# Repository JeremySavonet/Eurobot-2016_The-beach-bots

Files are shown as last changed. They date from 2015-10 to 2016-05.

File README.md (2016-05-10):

EUROBOT 2016 - The Beach Bots
====

TODO <br><br>

<h4>HW description:</h4>
----

Board : https://www.olimex.com/Products/ARM/ST/STM32-E407/open-source-hardware <br>
Motor Driver : https://www.olimex.com/Products/RobotParts/MotorDrivers/BB-VNH3SP30/open-source-hardware<br>
WiFi IoT module : https://www.olimex.com/Products/IoT/MOD-WIFI-ESP8266/open-source-hardware<br> 
=> Github : https://github.com/espressif/esp8266_at<br>

<h4>SW description:</h4>
----

Need to test those two RTOS:<br>

<li>Freertos : https://github.com/frtos-wpan/freertos-201309/tree/master/FreeRTOS/Demo/E407</li>
<li>ChibiOS : http://chibios.org/dokuwiki/doku.php?id=chibios:documentation:start</li>
    
Chibios seems to be a better alternative than FreeRtos for severals reasons:<br>
<li>maintaining our own hal eats a lot of development time - ChibiOS comes with a hal</li>
<li>pios hal is not being widely used and tested - ChibiOS is</li>
<li>FreeRTOS relies 100% on dynamic memory allocation (heap) - ChibiOS can do static as well as dynamic memory (even mixed)</li>
<li>FreeRTOS api is not type safe (mutex / semaphore / queue) - ChibiOS api is type safe</li>
<li>i have a feeling that ChibiOS is more efficient than FreeRTOS</li>
<li>using ChibiOS hal will make us stop relying on the buggy ST libraries in the longer term</li>

<h5>How to setup the env:</h5>

<li>Install arm gcc:</li>
<ul>brew tap PX4/homebrew-px4</ul>
<ul>brew update</ul>
<ul>brew install gcc-arm-none-eabi</ul>

<li>Install dfu-util:</li>
<ul>brew install dfu-util</ul>

<li>Make the projet:</li>
<ul>Just run make in the project folder</ul>

<li>Program the target:</li>
<ul>Put the device in dfu mode (set the jumper like explain in the manual</ul>
<ul>Run the command: dfu-util -v -d 0483:df11 -a 0 -s 0x08000000 -D prog.hex</ul>

<h4>Usefull links:</h4>
----

<li>https://www.alexwhittemore.com/using-the-stm32f4discovery-on-the-mac-os-x-10-8-4-command-line/</li>
<li>http://www.telecom-robotics.org/2013/08/robotics-101-quick-start/</li>

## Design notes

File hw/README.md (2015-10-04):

HW SECTION:
====

TODO:
----

<li> Add pull-up resistors </li>
<li> Update restrict zones </li>
<li> Update polygons clearance </li>

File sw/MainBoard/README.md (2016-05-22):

MAIN BOARD:
====

This project is a base project for our robot. It uses ChibiOS.
We have ported the control system management of Microb Tech originally develop
for AVR platform.

We also work with module as it's easier to understand and manage for the futur.

Here we describe the mapping use for this project for OLIMEX E407 Rev.E board:

<li>Encoders LEFT uses TIM3:</li>
    <ul>PB4 AF2</ul>
    <ul>PB5 AF2</ul>

<li>Encoders RIGHT uses TIM4:</li>
<ul>PD12 AF2</ul>
<ul>PD13 AF2</ul>

<li>Motors use TIM9:</li>
<ul>LEFT on PE5 AF3</ul>
<ul>RIGHT on PE6 AF3</ul>

<li>Microshell mapped on SDU2. User functions for now:</li>
<ul>ir : get ir module estimated distances</ul>
<ul>help : display a list off all available commands</ul>

<li>Debug UART on SDU3</li>

<li>IR sensors modules mapped on:</li>
<ul>IR1: PF6</ul>
<ul>IR2: PF7</ul>
<ul>IR3: PF8</ul>

<li>Can comm on CAN1</li>
<ul>CAN_RX: PD0/AF9</ul>
<ul>CAN_TX: PD1/AF9</ul>

TODO:
==

  * Add module status flag to monitor if they're are initialized or not
  * Rework FatFs to create log file with all sensors values
  * Add support for inertial board
  * I2C
  * Sys state machine
  * Deinit system

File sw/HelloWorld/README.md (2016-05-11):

HELLO WORLD:
====

This simple programm is here to demonstrate ChibiOS.
In this project we have a simple thread that blink a led and a CLI with basic
commands to test the perfomances of this OS.

Here we describe the mapping use for this project for OLIMEX E407 Rev.E board:

<li>Microshell mapped on SDU2. User functions for now:</li>
<ul>help : display a list off all available commands</ul>

<li>Debug UART on SDU3</li>

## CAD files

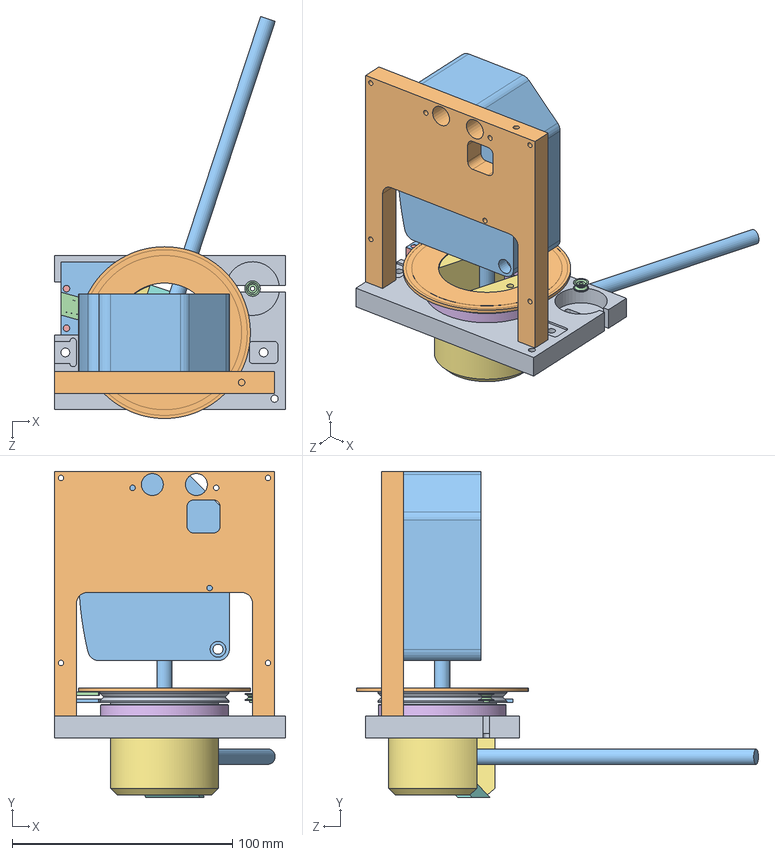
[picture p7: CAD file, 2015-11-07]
meca/10 telemetre laser/10 ass telemetre laser.SLDASM
105.0 x 148.2 x 182.6 mm
10.01 supp dessous telemetre
10.02 supp vertical telemetre
10.00 telemetre laser
10.00 poulie moteur HV
10.03 supp fourche optique
10.00 roulement miroir x 2
10.04 supp miroir
10.05 miroir telemetre
10.06 poulie entrainement telemetre
10.07 roue optique telemetre
10.11 carte elec dessous
10.13 fentes led

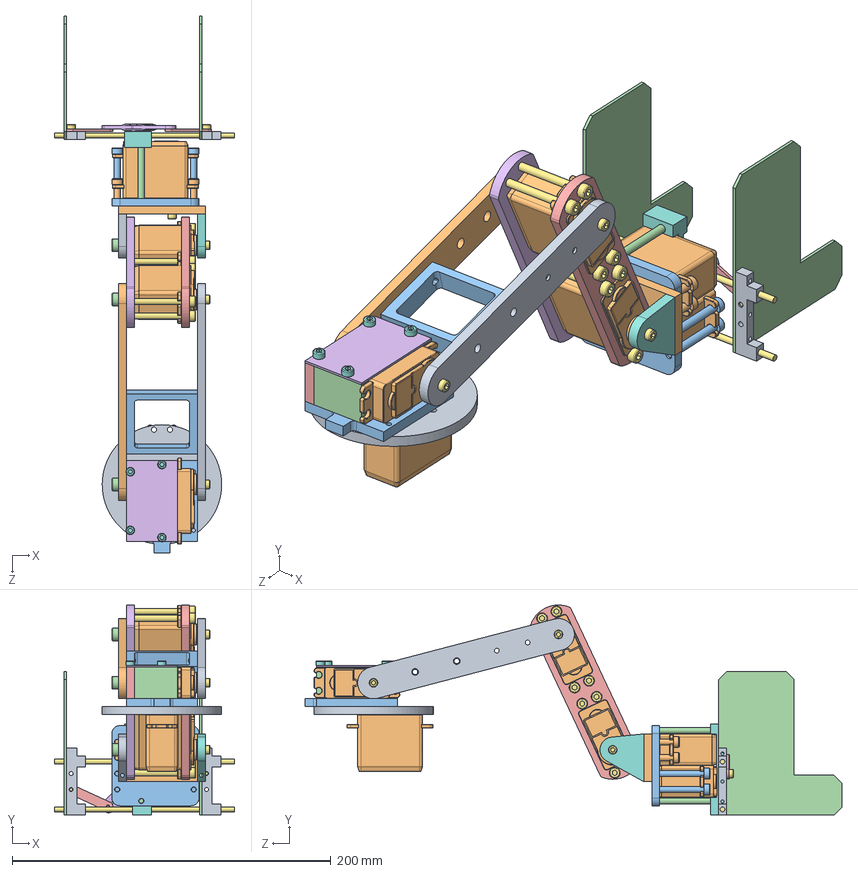
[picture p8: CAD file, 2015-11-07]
meca/12 bras/11.00 ass bras.SLDASM
113.0 x 131.8 x 337.0 mm
12.01 base
servo moteur MG995 x 6
12.11 rot bras
12.12 rot bras x 2
12.13 rot bras
12.14 rot bras
vis - chcm3 - 6 x 8
vis - chcm3 - 25 - 6 x 4
12.21 bras 1
12.22 bras 1
12.23 bras 1
vis - shs4 - 5 x 3
12.24 bras 2
12.25 bras 2
vis - chcm4 - 39 x 8
12.31 sup pince
12.32 sup pince
12.33 rot pince
12.34 rot pince
12.52 pince pile x 2
12.51 pince bielette x 2
bielette 2 bras - servo moteur MG995
12.61 tige x 2
12.62 sup tige
12.63 sup mors x 2
vis - chcm4 - 13 x 4
vis - chcm4 - 32 x 4
vis - chcm4 - 42 x 2

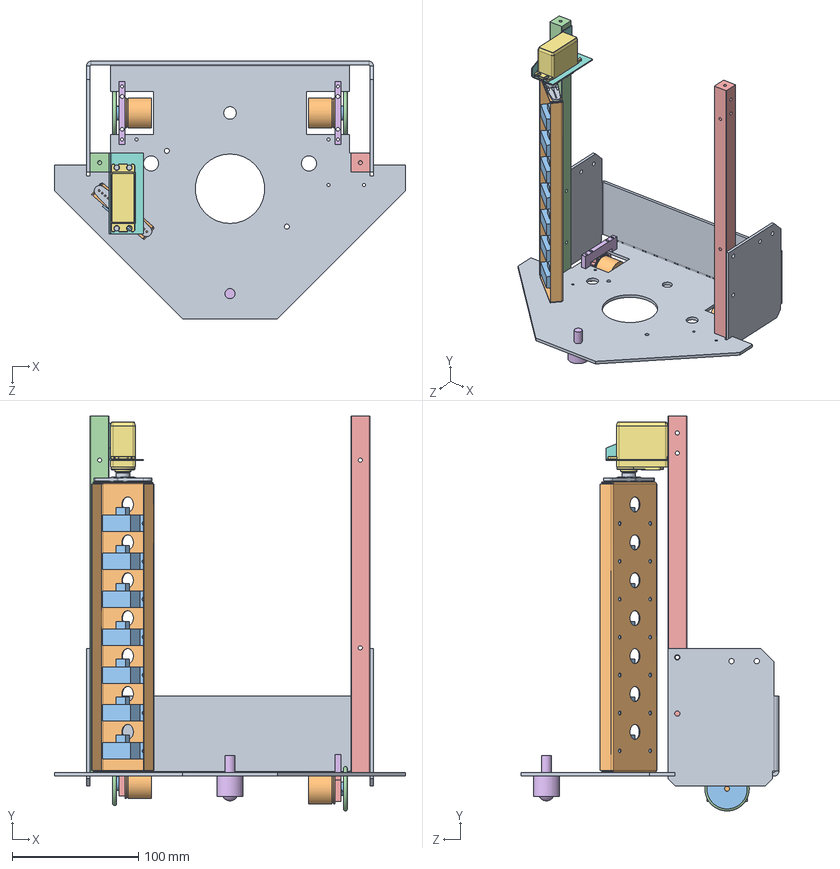
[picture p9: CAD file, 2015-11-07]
meca/Robot 2015.SLDASM
278.0 x 312.6 x 204.0 mm
01.01 chassis
04.01 supp telemetres
22.01 telemetre x 7
01.02 montant gauche
01.02 montant droit
02.02 roue folle
servo moteur MG995
04.02 supp servo telemetres
bielette 2 bras - servo moteur MG995
03.01 codeurs x 2
03.02 roue codeuse x 2
03.03 joint roue codeuse x 2
03.04 supp codeurs x 2
03.05 base codeurs x 2

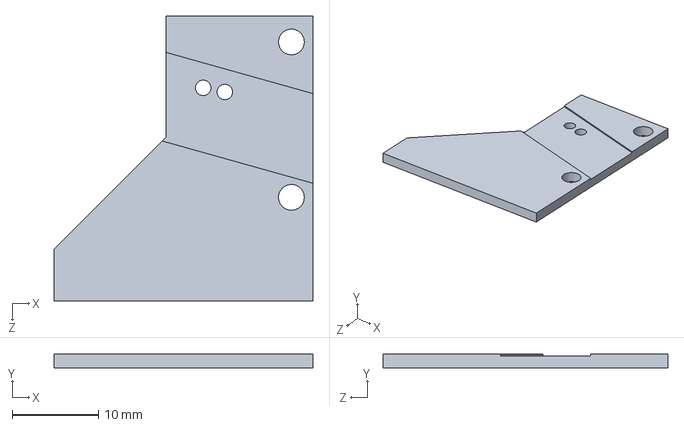
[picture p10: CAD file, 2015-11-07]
meca/10 telemetre laser/10.11 carte elec dessous.SLDPRT
30.0 x 1.60 x 33.0 mm

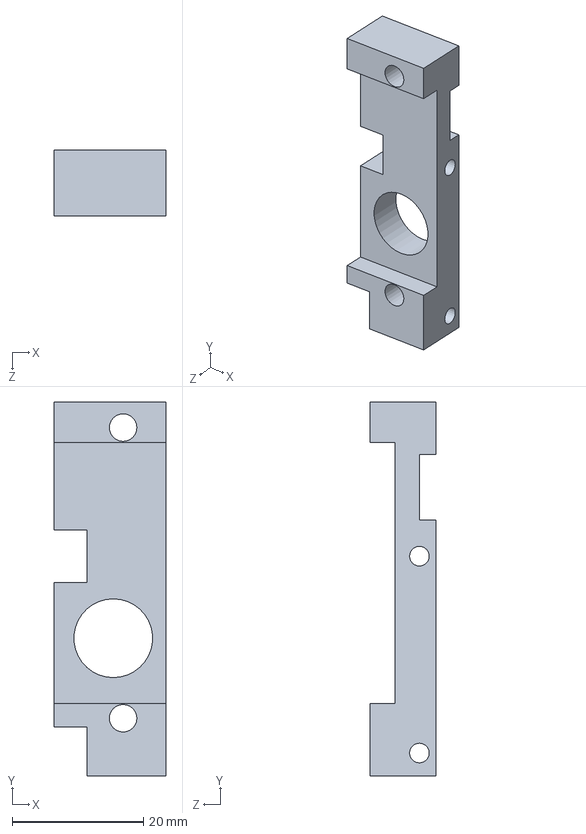
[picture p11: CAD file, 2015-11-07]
meca/12 bras/12.62 sup tige.SLDPRT
17.0 x 57.0 x 10.0 mm

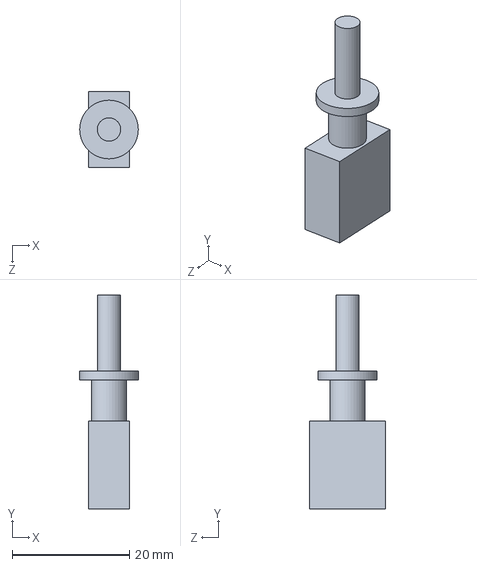
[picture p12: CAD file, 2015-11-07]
meca/21.03 int couleur.SLDPRT
10.0 x 36.5 x 13.0 mm

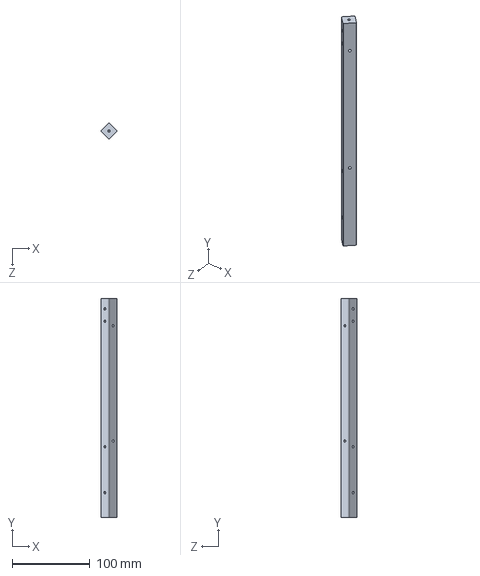
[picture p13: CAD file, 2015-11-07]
meca/01.02 montant gauche.SLDPRT
20.8 x 282.0 x 20.8 mm

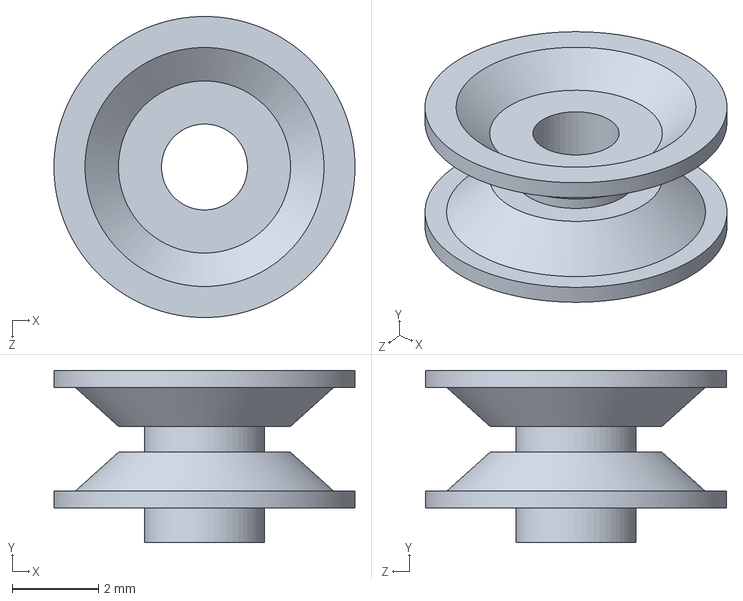
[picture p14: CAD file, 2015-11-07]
meca/10 telemetre laser/10.00 poulie moteur HV.SLDPRT
7.00 x 4.00 x 7.00 mm

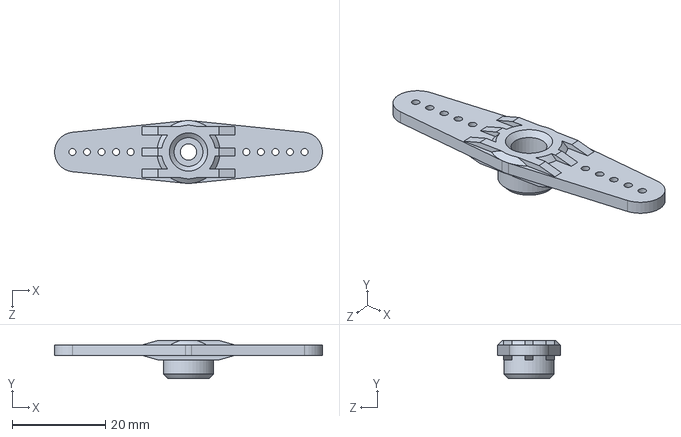
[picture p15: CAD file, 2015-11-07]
meca/12 bras/bielette 2 bras - servo moteur MG995.SLDPRT
57.5 x 8.20 x 13.5 mm

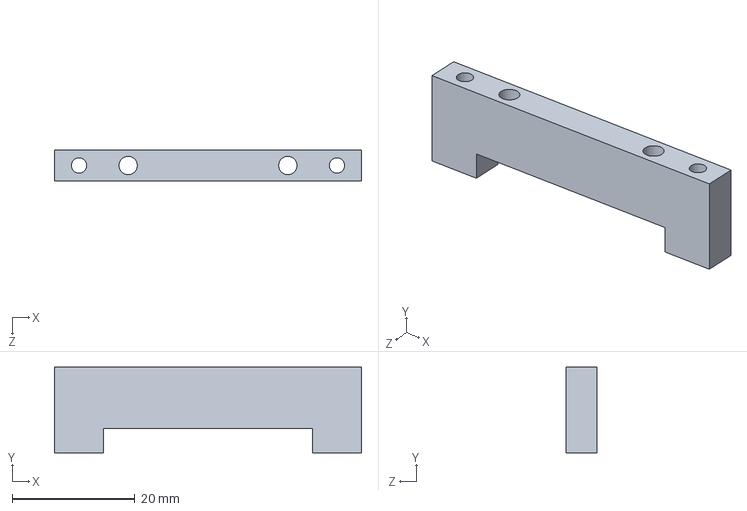
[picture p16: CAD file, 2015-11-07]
meca/03.05 base codeurs.SLDPRT
50.0 x 14.0 x 5.00 mm

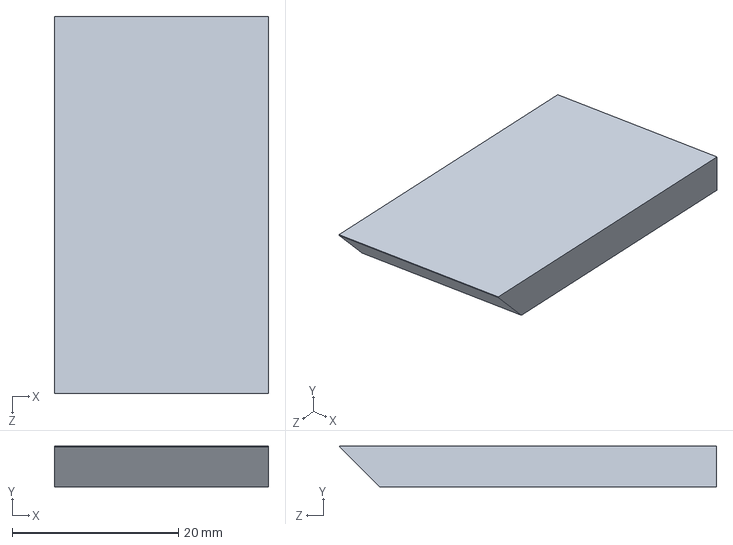
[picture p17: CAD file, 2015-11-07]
meca/10 telemetre laser/10.05 miroir telemetre.SLDPRT
25.8 x 4.90 x 45.3 mm

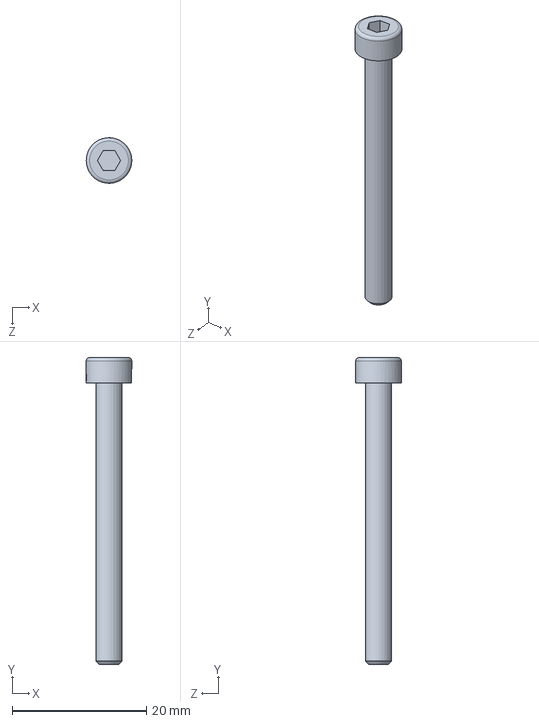
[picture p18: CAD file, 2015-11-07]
meca/12 bras/vis - chcm4 - 42.sldprt
6.79 x 45.8 x 6.80 mm

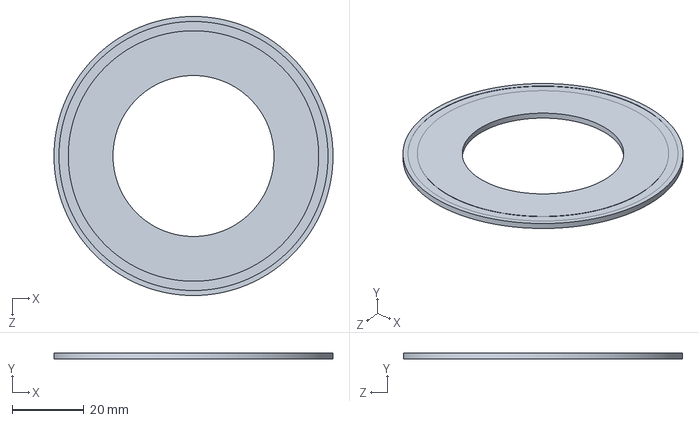
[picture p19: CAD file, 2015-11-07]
meca/10 telemetre laser/10.07 roue optique telemetre.SLDPRT
78.0 x 1.60 x 78.0 mm

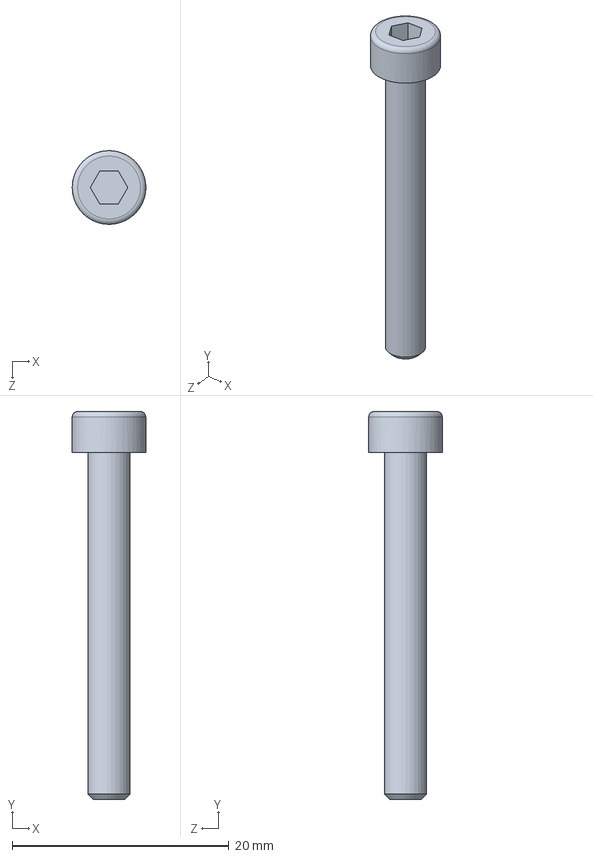
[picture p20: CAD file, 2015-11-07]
meca/12 bras/vis - chcm4 - 32.sldprt
6.79 x 35.8 x 6.80 mm

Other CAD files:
meca/bielette 2 bras - servo moteur MG995.SLDPRT
meca/10 telemetre laser/10.04 supp miroir.SLDPRT
meca/12 bras/12.33 rot pince.SLDPRT
meca/01.01 chassis.SLDPRT
meca/02.02 roue folle.SLDPRT
meca/03.01 codeurs.SLDPRT
meca/03.02 roue codeuse.SLDPRT
meca/03.03 joint roue codeuse.SLDPRT
meca/03.04 supp codeurs.SLDPRT
meca/04.01 supp telemetres.SLDPRT
meca/04.02 supp servo telemetres.SLDPRT
meca/10 telemetre laser/10.00 fourche optique.SLDPRT
meca/10 telemetre laser/10.00 roulement miroir.SLDPRT
meca/10 telemetre laser/10.00 telemetre laser.SLDPRT
meca/10 telemetre laser/10.01 supp dessous telemetre.SLDPRT
meca/10 telemetre laser/10.02 supp vertical telemetre.SLDPRT
meca/10 telemetre laser/10.03 supp fourche optique.SLDPRT
meca/10 telemetre laser/10.06 poulie entrainement telemetre.SLDPRT
meca/10 telemetre laser/10.13 fentes led.SLDPRT
meca/12 bras/12.01 base.SLDPRT
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

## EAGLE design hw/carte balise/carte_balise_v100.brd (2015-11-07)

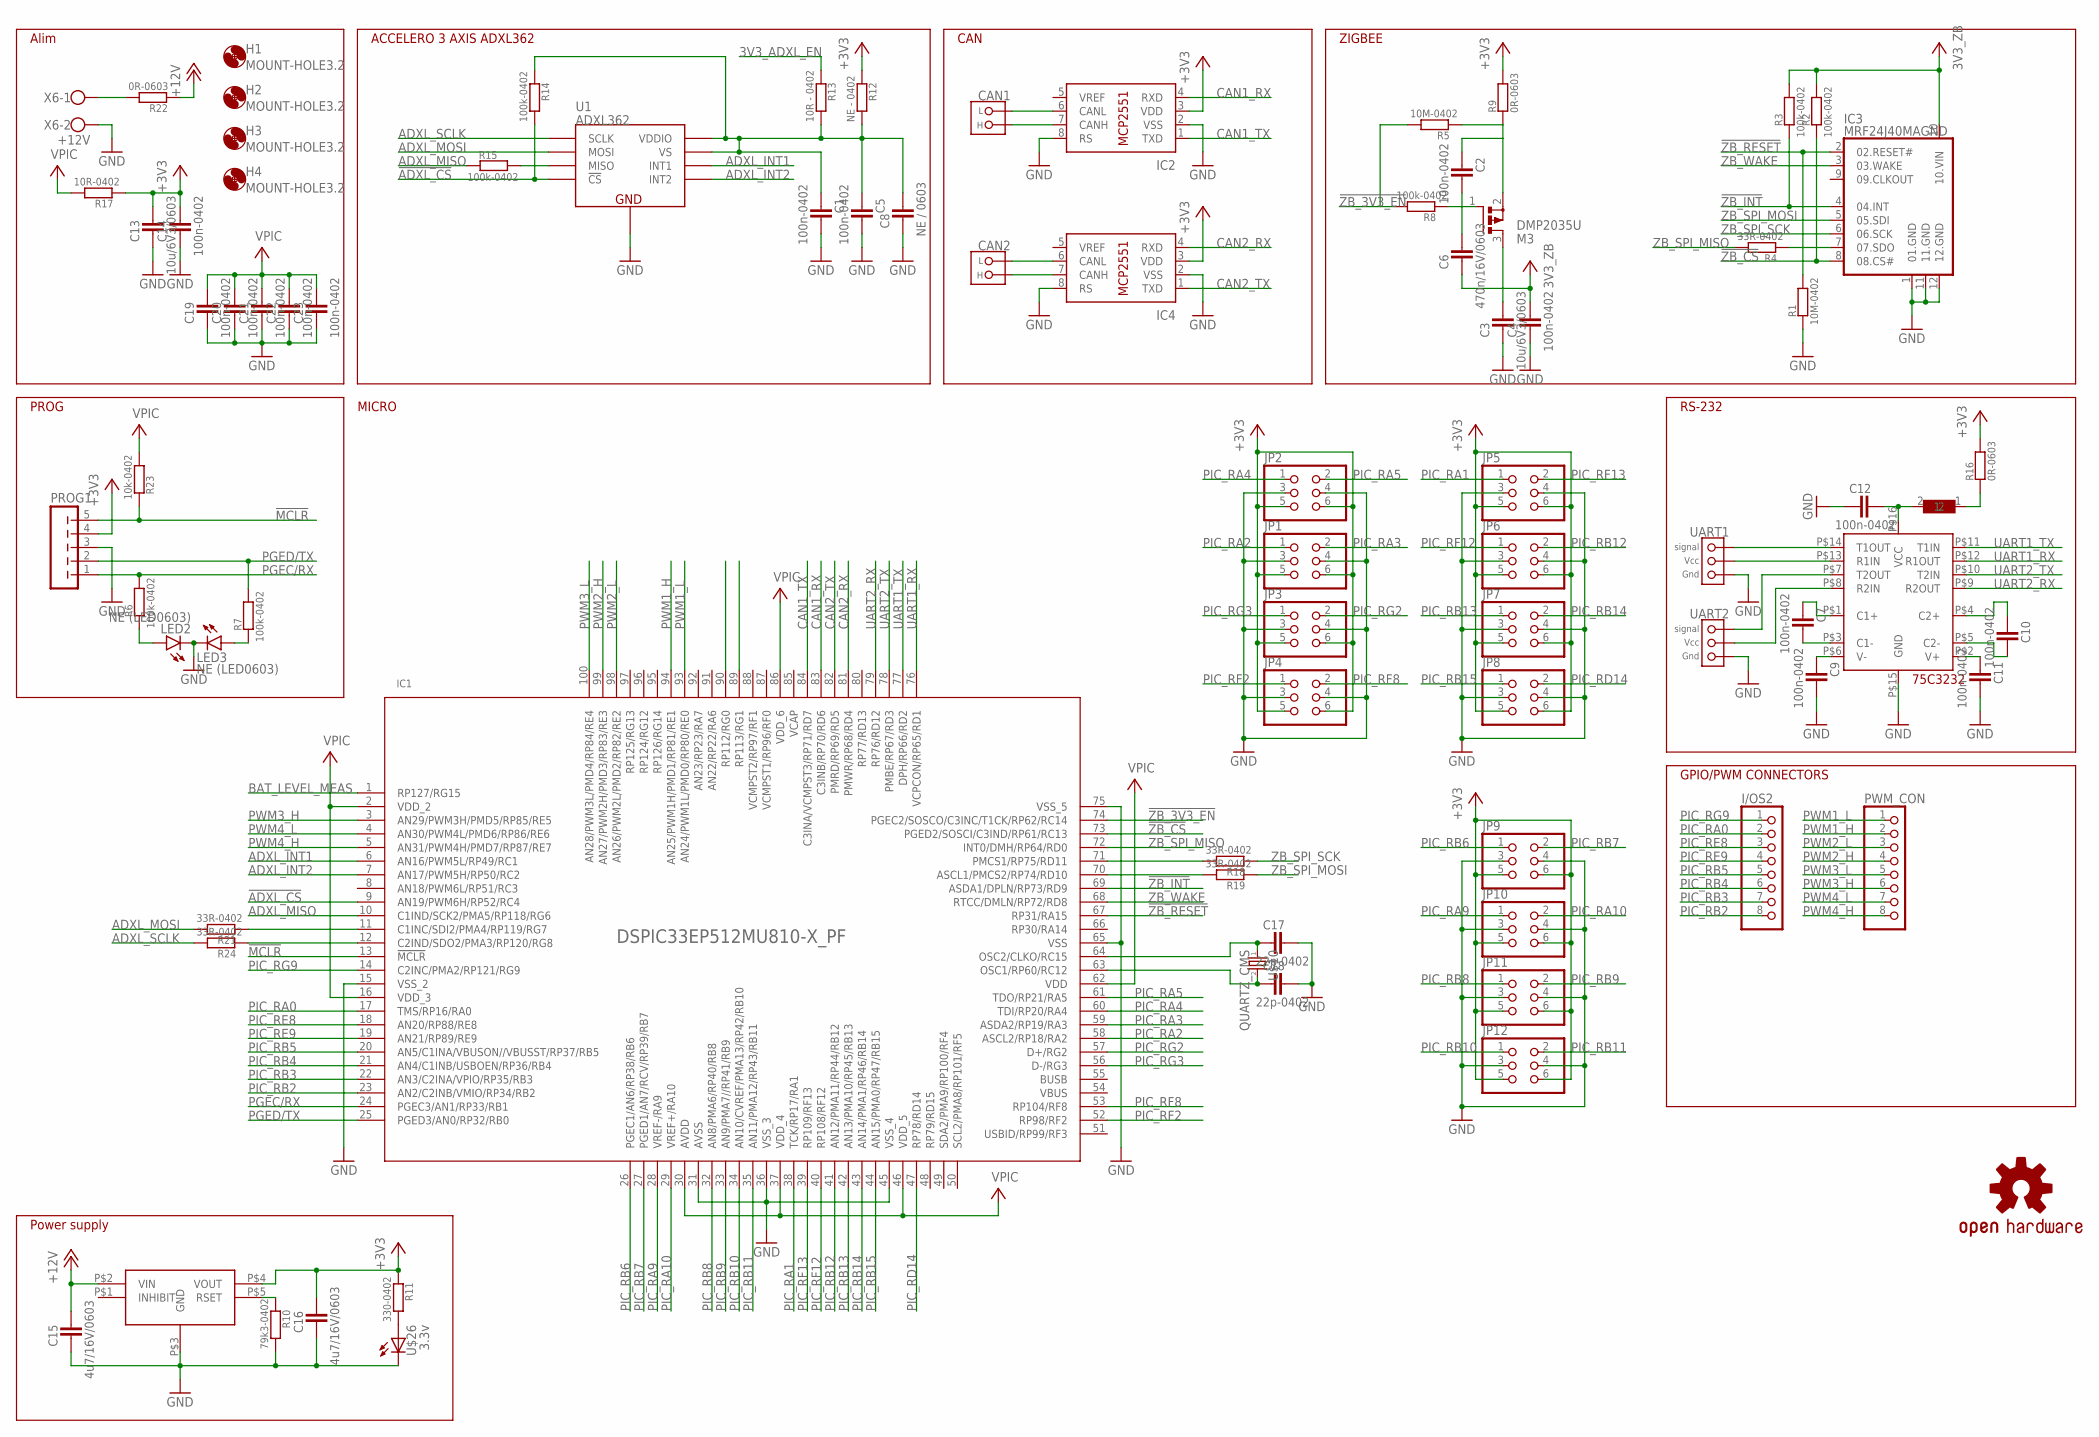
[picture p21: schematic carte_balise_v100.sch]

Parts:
C1, C2, C4, C5, C7, C9, C10, C11, C12, C14, C19, C20, C21, C22, C23: 100n-0402; 0402K
C3, C13: 10u/6V3/0603; 0603K
C6: 470n/16V/0603; 0603K
C8: NE / 0603; 0603K
C15, C16: 4u7/16V/0603; 0603K
C17, C18: 22p-0402; 0402K
CAN1, CAN2: CONNECT_CAN
H1, H2, H3, H4: MOUNT-HOLE3.2; 3,2
I/OS2: PINHD-1X08_2.54; 1X08
IC1: DSPIC33EP512MU810-X_PF; TQFP100_14X14MC
IC2, IC4: MCP2551/SN; SO08
IC3: MRF24J40MAGND; MRF24J40MA_2
JP1, JP2, JP3, JP4, JP5, JP6, JP7, JP8, JP9, JP10, JP11, JP12: PINHD-2X3; 2X03
LED2, LED3: NE (LED0603); 0603K
M3: DMP2035U; SOT23-3
PROG1: FE05-1
PWM_CON: PINHD-1X08_2.54; 1X08
R1, R5: 10M-0402; 0402K
R2, R3, R6, R7, R8, R14, R15: 100k-0402; 0402K
R4, R18, R19, R21, R24: 33R-0402; 0402K
R9, R16, R22: 0R-0603; 0603K
R10: 79k3-0402; 0402K
R11: 330-0402; 0402K
R12: NE - 0402; 0402K
R13: 10R - 0402; 0402K
R17: 10R-0402; 0402K
R23: 10k-0402; 0402K
U1: ADXL362
U$1: OSHW-LOGOS; OSHW-LOGO-S
U$2: SN75C3232_PW; PW16
U$3: L_603; 0603
U$10: QUARTZ_CMS
U$26: 3.3v; 805
U$27: PTR08100W
UART1, UART2: CONNECT_3PINS_CMS; CON_2.54_3
X6: +12V; W237-102

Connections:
3V3_ADXL_EN: R13.1
!ADXL_CS: IC1.9 (AN19/PWM6H/RP52/RC4), R14.2, U1.P$8 (!CS)
!MCLR: IC1.13 (!MCLR), PROG1.5, R23.1
!ZB_3V3_EN: IC1.74 (PGEC2/SOSCO/C3INC/T1CK/RP62/RC14), R5.2, R8.2
!ZB_CS: IC1.73 (PGED2/SOSCI/C3IND/RP61/RC13), IC3.8 (08.CS#), R2.1
!ZB_INT: IC1.69 (ASDA1/DPLN/RP73/RD9), IC3.4 (04.INT), R3.1
!ZB_RESET: IC1.67 (RP31/RA15), IC3.2 (02.RESET#), R1.2
+3V3: C13.1, C14.1, C16.1, IC2.3 (VDD), IC4.3 (VDD), JP1.5, JP1.6, JP2.5, JP2.6, JP3.5, JP3.6, JP4.5, JP4.6, JP5.5, JP5.6, JP6.5, JP6.6, JP7.5, JP7.6, JP8.5, JP8.6, JP9.5, JP9.6, JP10.5, JP10.6, JP11.5, JP11.6, JP12.5, JP12.6, PROG1.4, R9.2, R11.1, R12.1, R16.2, R17.1, U$27.P$4 (VOUT)
+12V: C15.1, R22.1, U$27.P$2 (VIN)
ADXL_INT1: IC1.6 (AN16/PWM5L/RP49/RC1), U1.P$11 (INT1)
ADXL_INT2: IC1.7 (AN17/PWM5H/RP50/RC2), U1.P$9 (INT2)
ADXL_MISO: IC1.10 (C1IND/SCK2/PMA5/RP118/RG6), R15.1
ADXL_MOSI: R21.2, U1.P$6 (MOSI)
ADXL_SCLK: R24.2, U1.P$4 (SCLK)
BAT_LEVEL_MEAS: IC1.1 (RP127/RG15)
BUSB: IC1.55 (BUSB)
CAN1_RX: IC1.83 (C3INB/RP70/RD6), IC2.4 (RXD)
CAN1_TX: IC1.84 (C3INA/VCMPST3/RP71/RD7), IC2.1 (TXD)
CAN2_RX: IC1.81 (PMWR/RP68/RD4), IC4.4 (RXD)
CAN2_TX: IC1.82 (PMRD/RP69/RD5), IC4.1 (TXD)
GND: C1.1, C3.2, C4.2, C5.1, C8.2, C9.1, C11.1, C12.2, C13.2, C14.2, C15.2, C16.2, C17.1, C18.1, C19.2, C20.2, C21.2, C22.2, C23.2, IC1.15 (VSS_2), IC1.31 (AVSS), IC1.36 (VSS_3), IC1.45 (VSS_4), IC1.65 (VSS), IC1.75 (VSS_5), IC2.2 (VSS), IC2.8 (RS), IC3.1 (01.GND), IC3.11 (11.GND), IC3.12 (12.GND), IC4.2 (VSS), IC4.8 (RS), JP1.3, JP1.4, JP2.3, JP2.4, JP3.3, JP3.4, JP4.3, JP4.4, JP5.3, JP5.4, JP6.3, JP6.4, JP7.3, JP7.4, JP8.3, JP8.4, JP9.3, JP9.4, JP10.3, JP10.4, JP11.3, JP11.4, JP12.3, JP12.4, LED2.K (C), LED3.K (C), PROG1.3, R1.1, R10.2, U1.P$12 (GND), U1.P$13 (GND), U1.P$16 (GND), U$2.P$15 (GND), U$26.2 (K), U$27.P$3 (GND), UART1.P$1 (_GND), UART2.P$1 (_GND), X6.2
unnamed: C2.1, C6.1, M3.1 (G), R8.1
unnamed: C2.2, M3.2 (S), R5.1, R9.1
unnamed: U$2.P$14 (T1OUT), UART1.P$3 (_SIGN)
unnamed: C1.2, C5.2, C8.1, R12.2, R13.2, R14.1, U1.P$1 (VDDIO), U1.P$14 (VS)
unnamed: R15.2, U1.P$7 (MISO)
unnamed: U$2.P$13 (R1IN), UART1.P$2 (_VCC)
unnamed: IC3.7 (07.SDO), R4.1
unnamed: CAN2._L, IC4.6 (CANL)
unnamed: C7.2, U$2.P$1 (C1+)
unnamed: IC1.12 (C2IND/SDO2/PMA3/RP120/RG8), R24.1
unnamed: LED2.A, R6.1
unnamed: C9.2, U$2.P$6 (V-)
unnamed: LED3.A, R7.1
unnamed: C7.1, U$2.P$3 (C1-)
unnamed: C11.2, U$2.P$2 (V+)
unnamed: C10.1, U$2.P$5 (C2-)
unnamed: C10.2, U$2.P$4 (C2+)
unnamed: C12.1, U$2.P$16 (VCC), U$3.2
unnamed: R16.1, U$3.1
unnamed: CAN1._L, IC2.6 (CANL)
unnamed: CAN1._H, IC2.7 (CANH)
unnamed: CAN2._H, IC4.7 (CANH)
unnamed: R11.2, U$26.1 (A)
unnamed: IC1.71 (PMCS1/RP75/RD11), R18.2
unnamed: U$2.P$7 (T2OUT), UART2.P$3 (_SIGN)
unnamed: U$2.P$8 (R2IN), UART2.P$2 (_VCC)
unnamed: C18.2, IC1.63 (OSC1/RP60/RC12), U$10.P$2 (2)
unnamed: C17.2, IC1.64 (OSC2/CLKO/RC15), U$10.P$1 (1)
unnamed: R22.2, X6.1
unnamed: IC1.11 (C1INC/SDI2/PMA4/RP119/RG7), R21.1
unnamed: IC1.70 (ASCL1/PMCS2/RP74/RD10), R19.2
unnamed: R10.1, U$27.P$5 (RSET)
PGEC/RX: IC1.24 (PGEC3/AN1/RP33/RB1), PROG1.1, R6.2
PGED/TX: IC1.25 (PGED3/AN0/RP32/RB0), PROG1.2, R7.2
PIC_RA0: I/OS2.2, IC1.17 (TMS/RP16/RA0)
PIC_RA1: IC1.38 (TCK/RP17/RA1), JP5.1
PIC_RA2: IC1.58 (ASCL2/RP18/RA2), JP1.1
PIC_RA3: IC1.59 (ASDA2/RP19/RA3), JP1.2
PIC_RA4: IC1.60 (TDI/RP20/RA4), JP2.1
PIC_RA5: IC1.61 (TDO/RP21/RA5), JP2.2
PIC_RA9: IC1.28 (VREF-/RA9), JP10.1
PIC_RA10: IC1.29 (VREF+/RA10), JP10.2
PIC_RB2: I/OS2.8, IC1.23 (AN2/C2INB/VMIO/RP34/RB2)
PIC_RB3: I/OS2.7, IC1.22 (AN3/C2INA/VPIO/RP35/RB3)
PIC_RB4: I/OS2.6, IC1.21 (AN4/C1INB/USBOEN/RP36/RB4)
PIC_RB5: I/OS2.5, IC1.20 (AN5/C1INA/VBUSON//VBUSST/RP37/RB5)
PIC_RB6: IC1.26 (PGEC1/AN6/RP38/RB6), JP9.1
PIC_RB7: IC1.27 (PGED1/AN7/RCV/RP39/RB7), JP9.2
PIC_RB8: IC1.32 (AN8/PMA6/RP40/RB8), JP11.1
PIC_RB9: IC1.33 (AN9/PMA7//RP41/RB9), JP11.2
PIC_RB10: IC1.34 (AN10/CVREF/PMA13/RP42/RB10), JP12.1
PIC_RB11: IC1.35 (AN11/PMA12/RP43/RB11), JP12.2
PIC_RB12: IC1.41 (AN12/PMA11/RP44/RB12), JP6.2
PIC_RB13: IC1.42 (AN13/PMA10/RP45/RB13), JP7.1
PIC_RB14: IC1.43 (AN14/PMA1/RP46/RB14), JP7.2
PIC_RB15: IC1.44 (AN15/PMA0/RP47/RB15), JP8.1
PIC_RD14: IC1.47 (RP78/RD14), JP8.2
PIC_RE8: I/OS2.3, IC1.18 (AN20/RP88/RE8)
PIC_RE9: I/OS2.4, IC1.19 (AN21/RP89/RE9)
PIC_RF2: IC1.52 (RP98/RF2), JP4.1
PIC_RF8: IC1.53 (RP104/RF8), JP4.2
PIC_RF12: IC1.40 (RP108/RF12), JP6.1
PIC_RF13: IC1.39 (RP109/RF13), JP5.2
PIC_RG2: IC1.57 (D+/RG2), JP3.2
PIC_RG3: IC1.56 (D-/RG3), JP3.1
PIC_RG9: I/OS2.1, IC1.14 (C2INC/PMA2/RP121/RG9)
PWM1_H: IC1.94 (AN25/PWM1H/PMD1/RP81/RE1), PWM_CON.2
PWM1_L: IC1.93 (AN24/PWM1L/PMD0/RP80/RE0), PWM_CON.1
PWM2_H: IC1.99 (AN27/PWM2H/PMD3/RP83/RE3), PWM_CON.4
PWM2_L: IC1.98 (AN26/PWM2L/PMD2/RP82/RE2), PWM_CON.3
PWM3_H: IC1.3 (AN29/PWM3H/PMD5/RP85/RE5), PWM_CON.6
PWM3_L: IC1.100 (AN28/PWM3L/PMD4/RP84/RE4), PWM_CON.5
PWM4_H: IC1.5 (AN31/PWM4H/PMD7/RP87/RE7), PWM_CON.8
PWM4_L: IC1.4 (AN30/PWM4L/PMD6/RP86/RE6), PWM_CON.7
UART1_RX: IC1.76 (VCPCON/RP65/RD1), U$2.P$12 (R1OUT)
UART1_TX: IC1.77 (DPH/RP66/RD2), U$2.P$11 (T1IN)
UART2_RX: IC1.79 (RP76/RD12), U$2.P$9 (R2OUT)
UART2_TX: IC1.78 (PMBE/RP67/RD3), U$2.P$10 (T2IN)
V+: C19.1, C20.1, C21.1, C22.1, C23.1, IC1.2 (VDD_2), IC1.16 (VDD_3), IC1.30 (AVDD), IC1.37 (VDD_4), IC1.46 (VDD_5), IC1.62 (VDD), IC1.86 (VDD_6), R17.2
VBUS: IC1.54 (VBUS)
VCAP: IC1.85 (VCAP)
VDD_RADIO: C3.1, C4.1, C6.2, IC3.10 (10.VIN), M3.3 (D), R2.2, R3.2
VPIC: R23.2
ZB_SPI_MISO: IC1.72 (INT0/DMH/RP64/RD0), R4.2
ZB_SPI_MOSI: IC3.5 (05.SDI), R19.1
ZB_SPI_SCK: IC3.6 (06.SCK), R18.1
ZB_WAKE: IC1.68 (RTCC/DMLN/RP72/RD8), IC3.3 (03.WAKE)

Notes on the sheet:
MICRO
ZIGBEE
Alim
ACCELERO 3 AXIS ADXL362
RS-232
CAN
Power supply
GPIO/PWM CONNECTORS
PROG

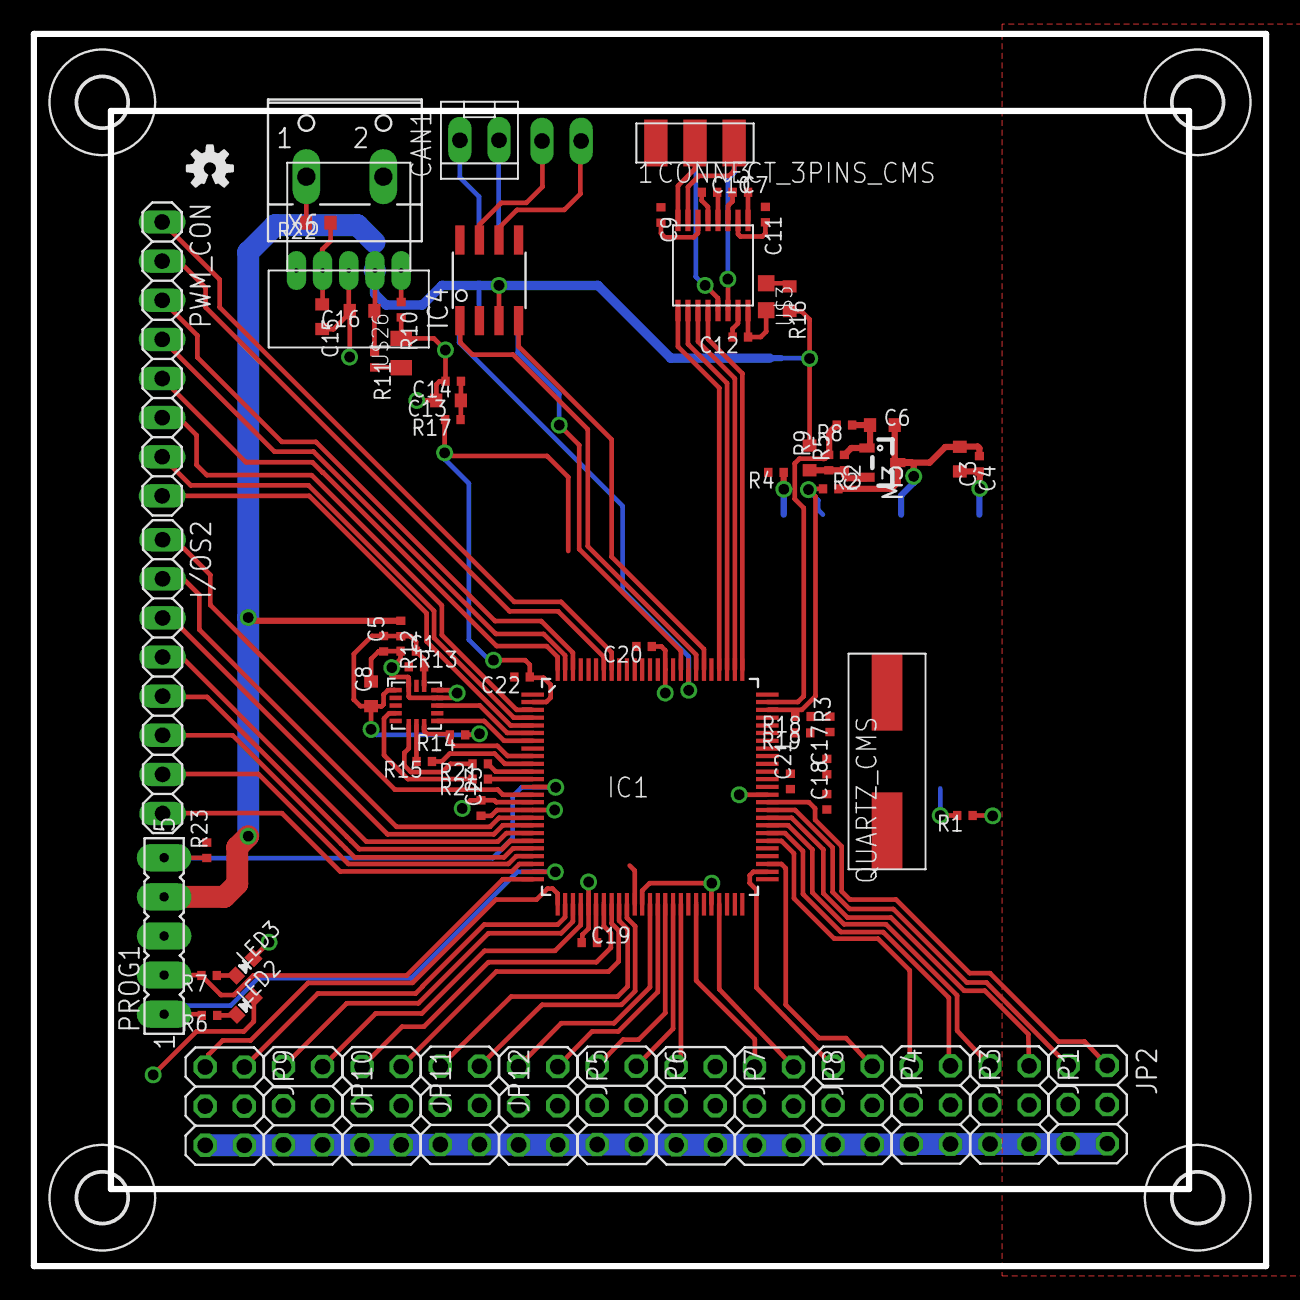
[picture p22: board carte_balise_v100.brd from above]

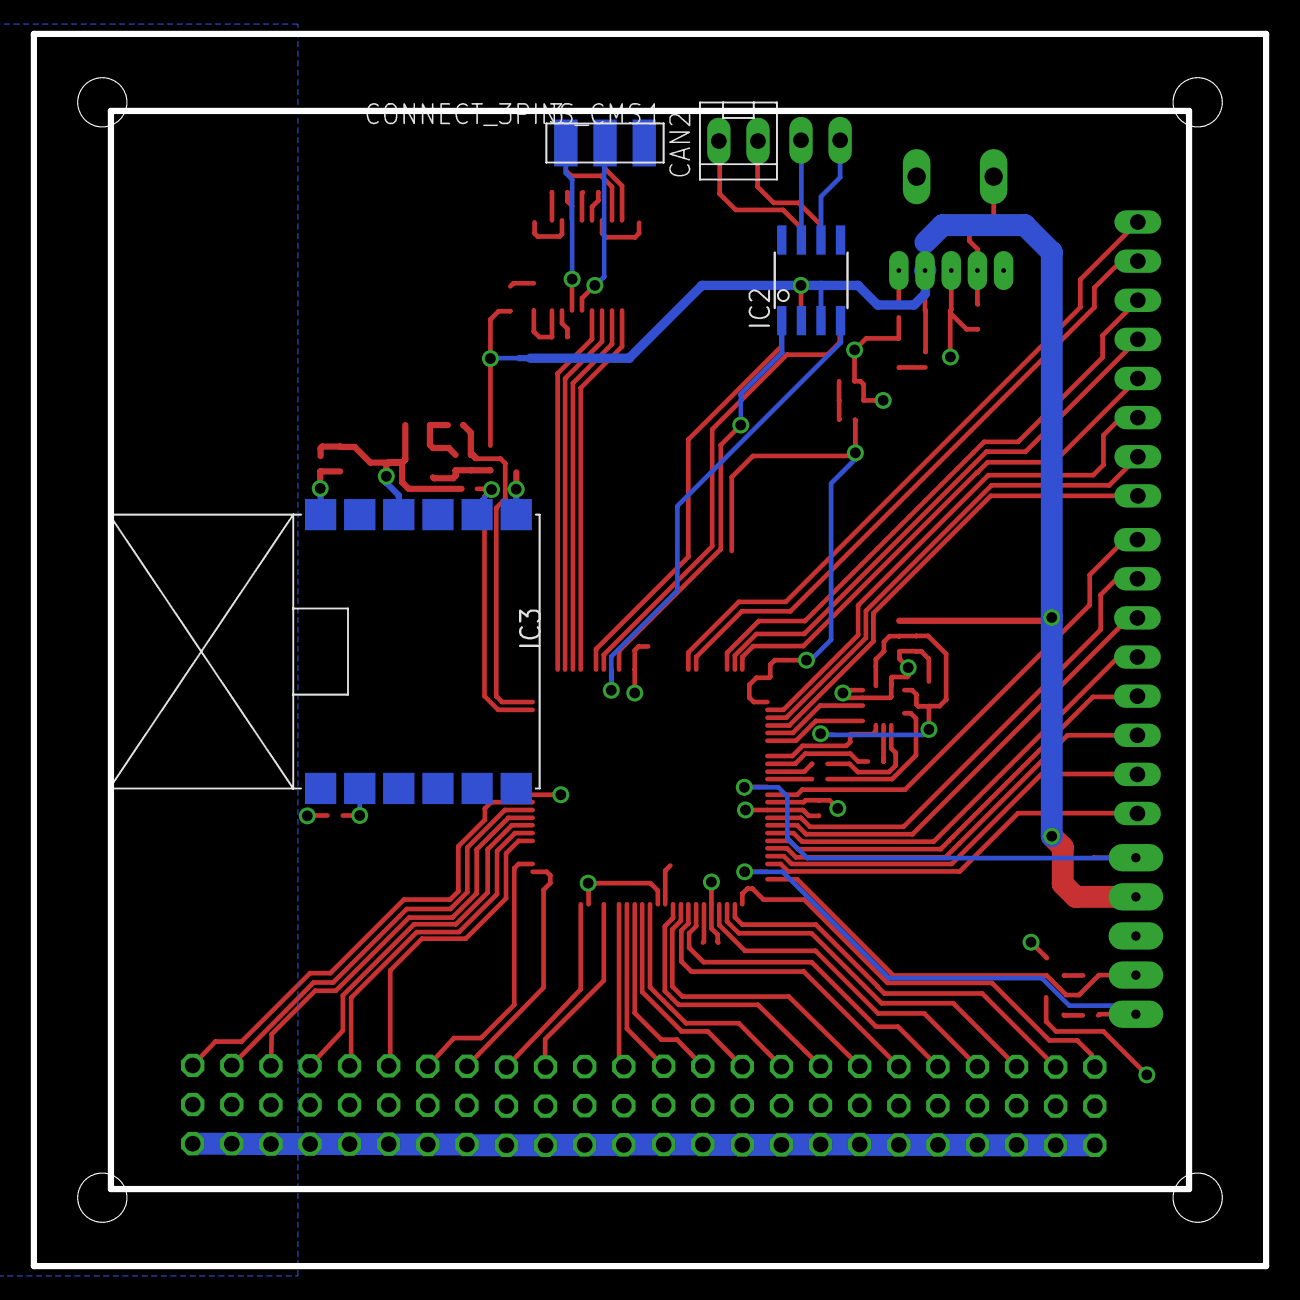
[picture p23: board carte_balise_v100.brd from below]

Board: 2 copper layers, 80.0 x 80.0 mm, 84 parts (4 on the bottom side), 102 nets.

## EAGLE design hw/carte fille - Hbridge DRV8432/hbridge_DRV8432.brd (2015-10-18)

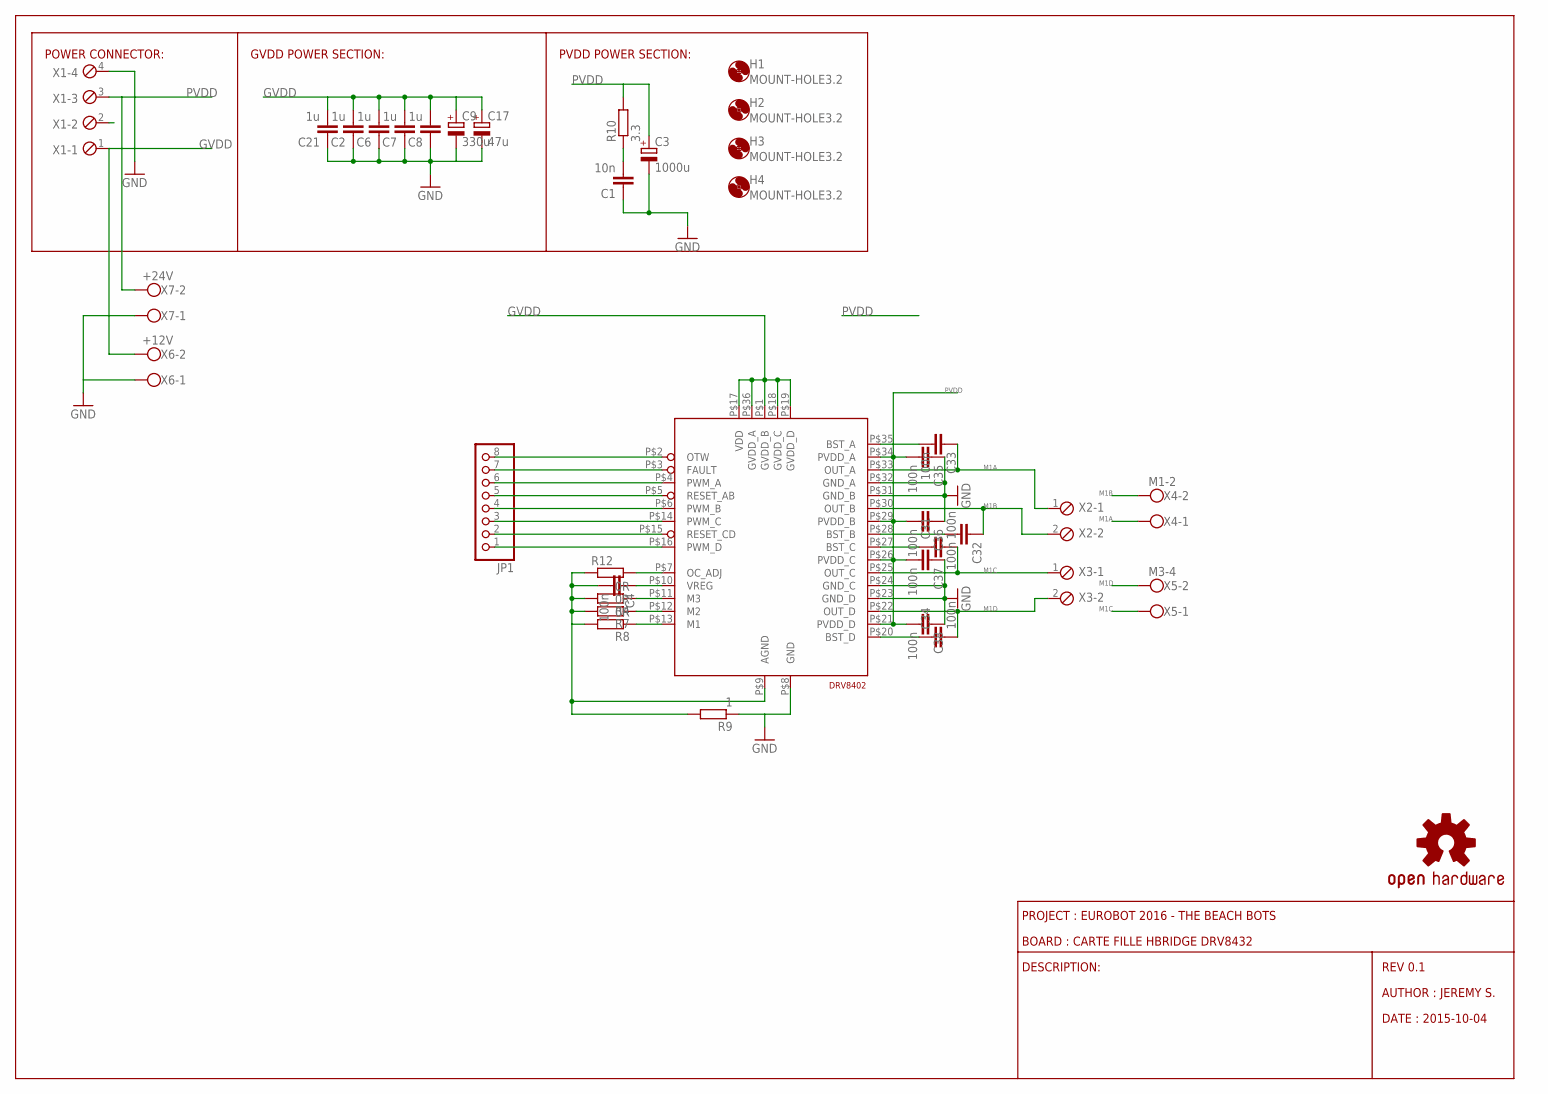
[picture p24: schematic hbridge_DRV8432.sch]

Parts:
C1: 10n; C0805
C2, C6, C7, C8, C21: 1u; C0805
C3: 1000u; E3,5-10
C4: 100n; C0603K
C9: 330u; B/3528-21W
C17: 47u; B/3528-21W
C31, C32, C33, C34: 100n; C0805
C35, C36, C37, C38: 100n; C0603
H1, H2, H3, H4: MOUNT-HOLE3.2; 3,2
IC1: DRV8402
JP1: PINHD-1X08_2.54; 1X08
R4, R7, R8: 0R; R0603
R9: 1; R0603
R10: 3.3; R1206
R12: R-EU_R0603; R0603
U$1: OSHW-LOGOS; OSHW-LOGO-S
X1: MPT4; 4POL254
X2, X3: MPT2; 2POL254
X4: M1-2; W237-102
X5: M3-4; W237-102
X6: +12V; W237-102
X7: +24V; W237-102

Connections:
GND: C1.1, C2.1, C3.-, C6.1, C7.1, C8.1, C9.-, C17.-, C21.1, C35.1, C36.1, C37.1, C38.1, IC1.P$8 (GND), IC1.P$23 (GND_D), IC1.P$24 (GND_C), IC1.P$31 (GND_B), IC1.P$32 (GND_A), R9.1, X1.4, X6.1, X7.1
GVDD: C2.2, C6.2, C7.2, C8.2, C9.+, C17.+, C21.2, IC1.P$1 (GVDD_B), IC1.P$17 (VDD), IC1.P$18 (GVDD_C), IC1.P$19 (GVDD_D), IC1.P$36 (GVDD_A), X1.1, X6.2
M1A: C33.1, IC1.P$33 (OUT_A), X2.1, X4.1
M1B: C32.1, IC1.P$30 (OUT_B), X2.2, X4.2
M1C: C31.2, IC1.P$25 (OUT_C), X3.1, X5.1
M1D: C34.2, IC1.P$22 (OUT_D), X3.2, X5.2
unnamed: IC1.P$2 (OTW), JP1.8
unnamed: IC1.P$13 (M1), R8.1
unnamed: IC1.P$12 (M2), R7.1
unnamed: IC1.P$11 (M3), R4.1
unnamed: IC1.P$3 (FAULT), JP1.7
unnamed: IC1.P$4 (PWM_A), JP1.6
unnamed: C4.2, IC1.P$9 (AGND), R4.2, R7.2, R8.2, R9.2, R12.1
unnamed: IC1.P$7 (OC_ADJ), R12.2
unnamed: C4.1, IC1.P$10 (VREG)
unnamed: C1.2, R10.1
unnamed: IC1.P$5 (RESET_AB), JP1.5
unnamed: IC1.P$6 (PWM_B), JP1.4
unnamed: IC1.P$14 (PWM_C), JP1.3
unnamed: IC1.P$15 (RESET_CD), JP1.2
unnamed: IC1.P$16 (PWM_D), JP1.1
unnamed: C33.2, IC1.P$35 (BST_A)
unnamed: C32.2, IC1.P$28 (BST_B)
unnamed: C31.1, IC1.P$27 (BST_C)
unnamed: C34.1, IC1.P$20 (BST_D)
PVDD: C3.+, C35.2, C36.2, C37.2, C38.2, IC1.P$21 (PVDD_D), IC1.P$26 (PVDD_C), IC1.P$29 (PVDD_B), IC1.P$34 (PVDD_A), R10.2, X1.3, X7.2

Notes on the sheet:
REV 0.1
AUTHOR : JEREMY S.
DATE : 2015-10-04
DESCRIPTION:
PROJECT : EUROBOT 2016 - THE BEACH BOTS
BOARD : CARTE FILLE HBRIDGE DRV8432
GVDD POWER SECTION:
POWER CONNECTOR:
PVDD POWER SECTION:

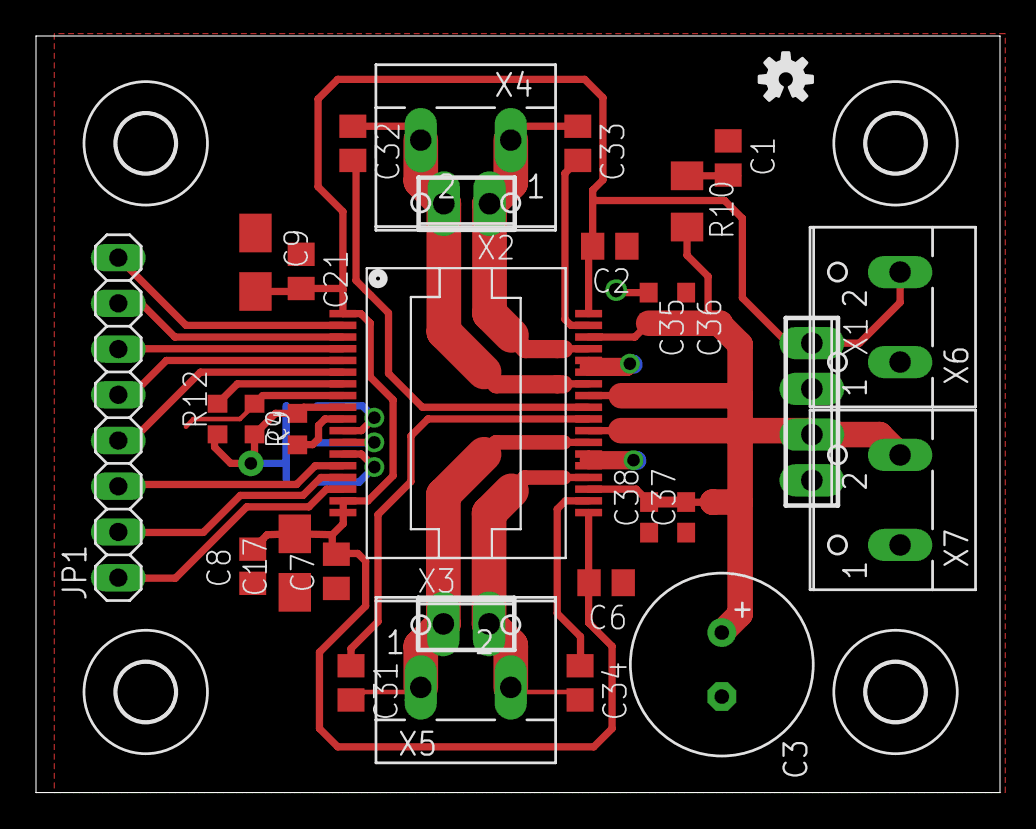
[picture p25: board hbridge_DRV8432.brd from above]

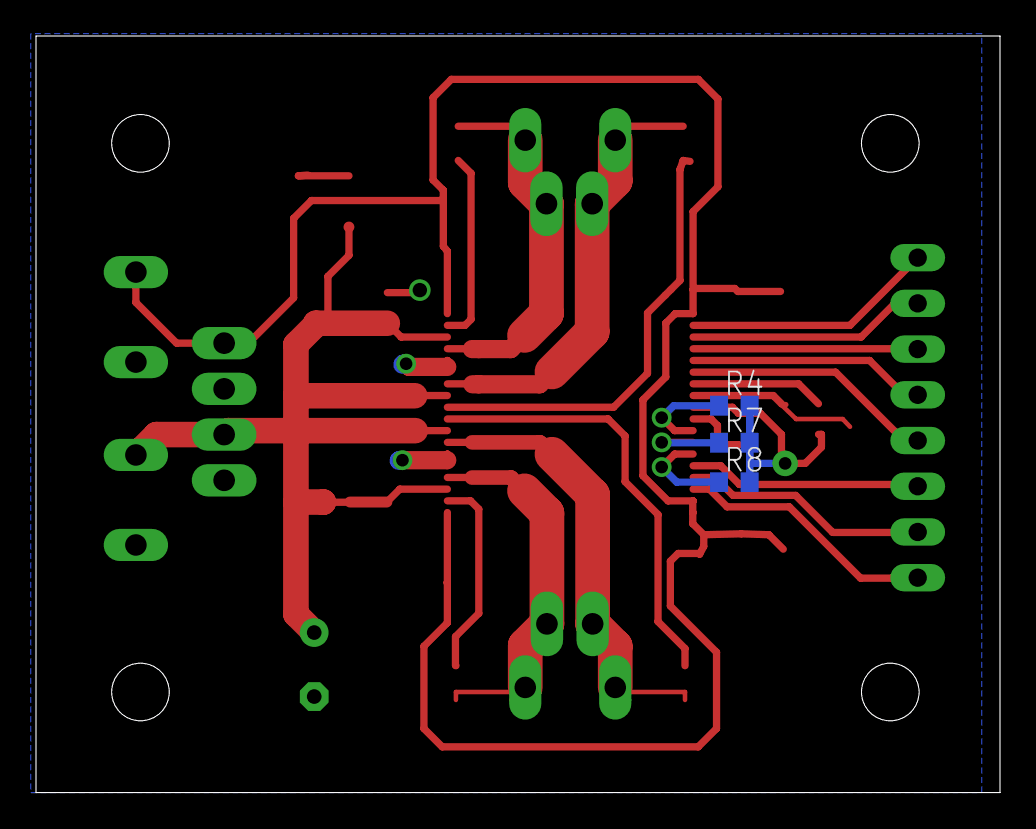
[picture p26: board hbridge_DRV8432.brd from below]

Board: 2 copper layers, 53.6 x 42.0 mm, 38 parts (3 on the bottom side), 26 nets.

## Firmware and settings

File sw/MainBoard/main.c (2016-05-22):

/*
 * Base software for non-holonome robot
 *
 * Description:
 * All the stuff related to make a non-holonome robot working.
 * See: system.c for board management
 * See: versatile_cs.c for robot control system stuff
 *
 * Added support for:
 * 90s timer to stop all the thread
 * Uart
 * UEXT reader thread
 * PWM on port D pin 12/13/14/15
 * ESP8266 API
 * CLI on USB2 OTG
 * MRF Zigbee chip
 *
 * Author: Jeremy S.
 * Date: 2015-10-03
 * Version: V1.0
 */

#include <stdio.h>
#include <string.h>

#include "ch.h"
#include "hal.h"
#include "test.h"

#include "system.h"

#include "versatile_cs.h"

#include "strat.h"

#include "color.h"
#include "comm/debug_manager.h"
#include "comm/microshell.h"

#include "modules/fatfs/fatfs_manager.h"

/*===========================================================================*/
/* Defines                                                                   */
/*===========================================================================*/

#define SHELL_WA_SIZE   THD_WORKING_AREA_SIZE( 2048 )

/*===========================================================================*/
/* Application threads                                                       */
/*===========================================================================*/

//Shell thread
static THD_WORKING_AREA( wa_cli, 2048 );
static THD_FUNCTION( CLI, arg )
{
    (void) arg;
    chRegSetThreadName( "CLI" );
    start_shell();
}

int main( void )
{
    // System unknown state
    sys.sys_state = SYSTEM_UNKNOWN;

    static thread_t *shelltp = NULL;

    /*
     * System initializations.
     * - HAL initialization, this also initializes the configured device drivers
     *   and performs the board-specific initializations.
     * - Kernel initialization, the main() function becomes a thread and the
     *   RTOS is active.
     */
    halInit();
    chSysInit();

    // Init system
    system_init();

    // Global main loop
    while( true )
    {
        if( !shelltp && ( SDU2.config->usbp->state == USB_ACTIVE ) )
        {
            shelltp = chThdCreateStatic( wa_cli,
                                         sizeof( wa_cli ),
                                         NORMALPRIO,
                                         CLI,
                                         NULL );
        }
        else if( chThdTerminatedX( shelltp ) )
        {
            chThdRelease( shelltp );  // Recovers memory of the previous shell.
            shelltp = NULL;           // Triggers spawning of a new shell.
        }
        
        fatfs_dispatch_event();

        chThdSleepMilliseconds( 100 ); // Iddle thread
    }
}

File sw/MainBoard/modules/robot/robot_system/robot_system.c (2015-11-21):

/*
 *  Copyright Droids Corporation, Microb Technology, Eirbot (2005)
 *
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
 *  Revision : $Id: robot_system.c,v 1.6.4.7 2009-03-29 18:48:23 zer0 Exp $
 *
 */

/*
 * The goal of this module is to provide an interface to motor and
 * encoders of the robot. This module provide a function that returns
 * the value of virtual encoders containing distance and angle. It
 * also allow the user to command virtual angle and distance PWMs.
 */

#include <string.h>
#include <stdio.h>

#include "../../../color.h"
#include "../../../comm/debug_manager.h"

#include "angle_distance.h"
#include "robot_system.h"

/*
 * Call a pwm pointer :
 *
 * This function reads the pointer to the PWM function and if the pointer is not
 * null call the set PWM function.
 *
 * [in] rs The robot_system instance.
 */
static inline
void safe_setpwm( void (*f)( void *, int32_t ), void * param, int32_t value )
{
    void (*f_tmp)( void *, int32_t );
    void * param_tmp;
    f_tmp = f;
    param_tmp = param;
    if( f_tmp )
    {
        f_tmp( param_tmp, value );
    }
}

/*
 * Call an encoder pointer :
 *
 * This function reads the pointer to the encoder function and if the pointer
 * is not null call the encoder function and return its result. If it is null,
 * then return 0.
 *
 * [in] rs The robot_system instance.
 *
 * Return The value of the encoder if defined, 0 otherwise.
 */
static inline
uint32_t safe_getencoder( int32_t (*f)( void * ), void * param )
{
    int32_t (*f_tmp)( void * );
    void * param_tmp;
    f_tmp = f;
    param_tmp = param;
    if( f_tmp )
    {
    	return f_tmp( param_tmp );
    }
    return 0;
}

void rs_init( struct robot_system * rs )
{
    memset( rs, 0, sizeof( struct robot_system ) );
#ifdef CONFIG_MODULE_ROBOT_SYSTEM_MOT_AND_EXT
    rs_set_ratio( rs, 1.0 );
#endif
}

#ifdef CONFIG_MODULE_ROBOT_SYSTEM_MOT_AND_EXT
void rs_set_ratio( struct robot_system * rs, double ratio )
{
    rs->ratio_mot_ext = ratio;
}
#endif

void rs_set_left_pwm( struct robot_system * rs,
                      void (*left_pwm)( void *, int32_t ),
                      void *left_pwm_param )
{
    rs->left_pwm = left_pwm;
    rs->left_pwm_param = left_pwm_param;
}

void rs_set_right_pwm( struct robot_system * rs,
                       void (*right_pwm)( void *, int32_t ),
                       void *right_pwm_param )
{
    rs->right_pwm = right_pwm;
    rs->right_pwm_param = right_pwm_param;
}

#ifdef CONFIG_MODULE_ROBOT_SYSTEM_MOT_AND_EXT
void rs_set_left_mot_encoder( struct robot_system * rs,
                              int32_t (*left_mot_encoder)( void * ),
			                  void *left_mot_encoder_param,
                              double gain )
{
    rs->left_mot_encoder = left_mot_encoder;
    rs->left_mot_encoder_param = left_mot_encoder_param;
    rs->left_mot_gain = gain;
}

void rs_set_right_mot_encoder( struct robot_system * rs,
                               int32_t (*right_mot_encoder)( void * ),
			                   void *right_mot_encoder_param,
                               double gain )
{
    rs->right_mot_encoder = right_mot_encoder;
    rs->right_mot_encoder_param = right_mot_encoder_param;
    rs->right_mot_gain = gain;
}
#endif

void rs_set_left_ext_encoder( struct robot_system * rs,
                              int32_t (*left_ext_encoder)( void * ),
			                  void *left_ext_encoder_param,
                              double gain )
{
    rs->left_ext_encoder = left_ext_encoder;
    rs->left_ext_encoder_param = left_ext_encoder_param;
    rs->left_ext_gain = gain;
}

void rs_set_right_ext_encoder( struct robot_system * rs,
                               int32_t (*right_ext_encoder)( void * ),
			                   void *right_ext_encoder_param,
                               double gain )
{
    rs->right_ext_encoder = right_ext_encoder;
    rs->right_ext_encoder_param = right_ext_encoder_param;
    rs->right_ext_gain = gain;
}

void rs_set_angle( void * data, int32_t angle )
{
    struct rs_polar p;
    struct rs_wheels w;
    struct robot_system * rs = data;
    p.distance = rs->virtual_pwm.distance ;
    rs->virtual_pwm.angle = angle;

    p.angle = angle;
    rs_get_wheels_from_polar( &w, &p );

    safe_setpwm( rs->left_pwm, rs->left_pwm_param, w.left );
    safe_setpwm( rs->right_pwm, rs->right_pwm_param, w.right );
}

void rs_set_distance( void * data, int32_t distance )
{
    struct robot_system * rs = data;
    struct rs_polar p;
    struct rs_wheels w;

    p.angle = rs->virtual_pwm.angle ;
    rs->virtual_pwm.distance = distance;

    p.distance = distance;
    rs_get_wheels_from_polar( &w, &p );

    safe_setpwm( rs->left_pwm, rs->left_pwm_param, w.left );
    safe_setpwm( rs->right_pwm, rs->right_pwm_param, w.right );
}

int32_t rs_get_angle( void * data )
{
    struct robot_system * rs = data;
    return rs->virtual_encoders.angle ;
}

int32_t rs_get_distance( void * data )
{
    struct robot_system * rs = data;
    return rs->virtual_encoders.distance ;
}

int32_t rs_get_ext_angle( void * data )
{
    struct robot_system * rs = data;
    return rs->pext_prev.angle ;
}

int32_t rs_get_ext_distance( void * data )
{
    struct robot_system * rs = data;
    return rs->pext_prev.distance ;
}

#ifdef CONFIG_MODULE_ROBOT_SYSTEM_MOT_AND_EXT
int32_t rs_get_mot_angle( void * data )
{
    struct robot_system * rs = data;
    return rs->pmot_prev.angle ;
}

int32_t rs_get_mot_distance( void * data )
{
    struct robot_system * rs = data;
    return  rs->pmot_prev.distance ;
}
#endif

int32_t rs_get_ext_left( void * data )
{
    struct robot_system * rs = data;
    return rs->wext_prev.left ;
}

int32_t rs_get_ext_right( void * data )
{
    struct robot_system * rs = data;
    return rs->wext_prev.right ;
}

#ifdef CONFIG_MODULE_ROBOT_SYSTEM_MOT_AND_EXT
int32_t rs_get_mot_left( void * data )
{
    struct robot_system * rs = data;
    return rs->wmot_prev.left ;
}

int32_t rs_get_mot_right( void * data )
{
    struct robot_system * rs = data;
    return rs->wmot_prev.right ;
}
#endif

void rs_set_flags( struct robot_system * rs, uint8_t flags )
{
    rs->flags = flags;
}

void rs_update( void * data )
{
    struct robot_system * rs = data;
    struct rs_wheels wext;
    struct rs_polar pext;
#ifdef CONFIG_MODULE_ROBOT_SYSTEM_MOT_AND_EXT
    struct rs_wheels wmot;
    struct rs_polar pmot;
#endif
    int32_t delta_angle, delta_distance;

    // read encoders
    wext.left = safe_getencoder( rs->left_ext_encoder,
                                 rs->left_ext_encoder_param );
    wext.right = safe_getencoder( rs->right_ext_encoder,
                                  rs->right_ext_encoder_param );
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

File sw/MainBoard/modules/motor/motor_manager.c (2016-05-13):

/*
 *  Low level motors driver module
 *  Manages motor speeds and sends them via PWM
 *  See : Trajectory Manager module
 */

#include "ch.h"
#include "hal.h"
#include "test.h"

#include "../../color.h"
#include "../../comm/debug_manager.h"

#include "motor_manager.h"

/*===========================================================================*/
/* PWM related.                                                              */
/*===========================================================================*/

static PWMConfig motor_pwm_cfg =
{
    1000000, // 1MHz PWM clock frequency
    20000,   // Initial PWM period 20ms ( 50hz (20ms) for standard servo/ESC, 400hz for fast servo/ESC (2.5ms = 2500) )
    NULL,    // No callback
    {
        { PWM_OUTPUT_ACTIVE_HIGH, NULL },
        { PWM_OUTPUT_ACTIVE_HIGH, NULL },
        { PWM_OUTPUT_DISABLED, NULL },
        { PWM_OUTPUT_DISABLED, NULL }
    },
    0,
#if STM32_PWM_USE_ADVANCED
    0,
#endif
    0
};

/*===========================================================================*/
/* QEI related.                                                              */
/*===========================================================================*/

static const QEIConfig motor_left_qei_cfg =
{
    QEI_MODE_QUADRATURE,
    QEI_BOTH_EDGES,
    QEI_DIRINV_FALSE
};

static const QEIConfig motor_right_qei_cfg =
{
    QEI_MODE_QUADRATURE,
    QEI_BOTH_EDGES,
    QEI_DIRINV_TRUE
};

void qei_manager_init( void )
{
    // Left encoder
    palSetPadMode( GPIOB, 4, PAL_MODE_ALTERNATE( 2 ) );
    palSetPadMode( GPIOB, 5, PAL_MODE_ALTERNATE( 2 ) );

    // Right encoder
    palSetPadMode( GPIOD, 12, PAL_MODE_ALTERNATE( 2 ) );
    palSetPadMode( GPIOD, 13, PAL_MODE_ALTERNATE( 2 ) );

    qeiStart( &MOTOR_LEFT_QEI_DRIVER, &motor_left_qei_cfg );
    qeiStart( &MOTOR_RIGHT_QEI_DRIVER, &motor_right_qei_cfg );

    qeiEnable( &MOTOR_LEFT_QEI_DRIVER );
    qeiEnable( &MOTOR_RIGHT_QEI_DRIVER );
}

void motor_manager_init( void )
{
    // Left/Right motors
    palSetPadMode( GPIOE, 5, PAL_MODE_ALTERNATE( 3 ) );
    palSetPadMode( GPIOE, 6, PAL_MODE_ALTERNATE( 3 ) );

    pwmStart( &MOTOR_PWM_DRIVER, &motor_pwm_cfg );

    unsigned i;
    for( i = 0; i < NUM_MOTORS; ++i )
    {
        versatile_dc_set_pwm( MOTOR_CONTROLLER_BASE, i, 0 );
    }
}

void versatile_dc_disable_pwm( void *device, int channel )
{
    if( channel < 0 || channel > NUM_MOTORS )
    {
        return;
    }

    pwmDisableChannel( device,
                       channel );
}

void versatile_dc_set_pwm( void *device, int channel, int32_t value )
{
    if( channel < 0 || channel > NUM_MOTORS )
    {
        return;
    }

    if( value < DC_PWM_MIN_VALUE )
    {
        value = DC_PWM_MIN_VALUE;
    }

    if( value > DC_PWM_MAX_VALUE )
    {
        value = DC_PWM_MAX_VALUE;
    }

    pwmEnableChannel( device,
                      channel,
                      (pwmcnt_t) value );
}

int32_t versatile_dc_get_encoder( void *device )
{
    uint16_t qei = qeiGetCount( (QEIDriver *) device );
    return qei;
}

void versatile_dc_set_pwm0( void *device, int32_t value )
{
    versatile_dc_set_pwm( device, 0, value );
}

void versatile_dc_set_pwm1( void *device, int32_t value )
{
    versatile_dc_set_pwm( device, 1, value );
}

void versatile_dc_set_pwm_negative0( void *device, int32_t value )
{
    versatile_dc_set_pwm( device, 0, -value );
}

void versatile_dc_set_pwm_negative1( void *device, int32_t value )
{
    versatile_dc_set_pwm( device, 1, -value );
}

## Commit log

2015-10-03 Add dev board datasheet and manual
2015-10-03 Add ChibiOS and simple demo program
    [stm_spc56ec74a256s_spc56ec74_minimodule_debug_jtag.cfg, stm_xpc560b64_minimodule_debug_jtag.cfg, stm_xpc560b_spc560d40_minimodule_debug_jtag.cfg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]
2015-10-04 HBridge board WIP
    [hbridge_DRV8432.brd, hbridge_DRV8432.sch]
2015-10-04 Cleanup ChibiOS folder
    [stm_spc56ec74a256s_spc56ec74_minimodule_debug_jtag.cfg, stm_xpc560b64_minimodule_debug_jtag.cfg, stm_xpc560b_spc560d40_minimodule_debug_jtag.cfg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]
2015-10-04 Fix issue with lwip and fatfs Update HelloWolrd project
    [main.c]
2015-10-04 Start routing the board
    [hbridge_DRV8432.brd, hbridge_DRV8432.sch]
2015-10-10 rework board routing
    [hbridge_DRV8432.brd, hbridge_DRV8432.sch]
2015-10-10 finish routing
    [hbridge_DRV8432.brd, hbridge_DRV8432.sch]
2015-10-11 fix power section
    [hbridge_DRV8432.brd]
2015-10-11 add openOCD config files for differents platform
    [olimex_stm32_e407.cfg, stm32f4discovery.cfg, stm32f4x.cfg]
2015-10-18 start balise mother board
    [carte_balise_v100.brd, carte_balise_v100.sch]
2015-10-18 add open hardware logo
    [hbridge_DRV8432.brd, hbridge_DRV8432.sch]
2015-10-18 rework io connector and start routing the board
    [carte_balise_v100.brd, carte_balise_v100.sch]
2015-10-24 add uart module on usart3
2015-10-24 adding gameloop and stop all the thread after 90s
2015-10-24 rework the way we finish thread processing
    [main.c]
2015-10-24 adding uext thread reader for modwifi
2015-10-25 project cleanup + fix ESP8266
    [main.c]
2015-10-25 add pwm support on port D with TIM4
2015-10-31 wip routing and placement
    [carte_balise_v100.brd, carte_balise_v100.sch]
2015-11-01 WIP adxl
    [carte_balise_v100.brd, carte_balise_v100.sch]
2015-11-02 wip board
    [carte_balise_v100.brd]
2015-11-07 start meca 2016
    [01.01 chassis.SLDPRT, 01.02 montant droit.SLDPRT, 01.02 montant gauche.SLDPRT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]
2015-11-08 rework debug print and add some cool stuff on boot sequence
    [main.c]
2015-11-08 start adc manager and cli module
2015-11-09 add altium balise project
    [carte_balise_v100.PcbDoc, carte_balise_v100.PrjPcb, carte_balise_v100.SchDoc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]
2015-11-14 project cleanup and rework folder architecture
    [main.c, motorsManager.c, motorsManager.h]
2015-11-14 wip on control system -> adding some filters
2015-11-15 rework debug print in new modules
2015-11-16 first attempt to pwm function pointer
2015-11-18 add debug to test pwm
2015-11-20 minor changes on pwm
2015-11-20 remap qei to TIM3/4 and PWM to TIM9. [ tested: ok]
2015-11-21 add ChibiOS 3.0.3 with STM32 QEI integration
    [stm_spc56ec74a256s_spc56ec74_minimodule_debug_jtag.cfg, stm_xpc560b64_minimodule_debug_jtag.cfg, stm_xpc560b_spc560d40_minimodule_debug_jtag.cfg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]
2015-11-21 add ir sensor module and htpp server integration
2015-11-21 fix command to return when wrong number of args
    [infrared.c]
2015-11-21 clean motor_manager modules and add usefull commands to the CLI
2015-11-22 rework infrared module. Add versatile_sensors manager. Update commands file
    [infrared.c]
2015-11-22 add temperature sensor module
2015-11-22 add battery manager module
2015-11-23 add commands to set/get pid gains
2016-05-11 Add main board project
2016-05-13 move motor module in right subfolder
2016-05-13 Change PWM value to match our ESC
2016-05-14 Add chibios 3.0.5
    [stm_spc56ec74a256s_spc56ec74_minimodule_debug_jtag.cfg, stm_xpc560b64_minimodule_debug_jtag.cfg, stm_xpc560b_spc560d40_minimodule_debug_jtag.cfg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]
2016-05-14 Add ChibiOS 16.1.4
    [stm_spc56ec74a256s_spc56ec74_minimodule_debug_jtag.cfg, stm_xpc560b64_minimodule_debug_jtag.cfg, stm_xpc560b_spc560d40_minimodule_debug_jtag.cfg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]
2016-05-14 Patch to support QEI driver for STM32F4XX platform (ChibiOS3.0.5)
2016-05-22 add brushless motor support
2016-05-22 fix in brushless motor module
    [brushless_motor_manager.c, brushless_motor_manager.h]
2016-05-22 rework sys state and add can support
    [main.c]
2016-10-09 repo cleanup
    [olimex_stm32_e407.cfg, stm32f4discovery.cfg, stm32f4x.cfg]

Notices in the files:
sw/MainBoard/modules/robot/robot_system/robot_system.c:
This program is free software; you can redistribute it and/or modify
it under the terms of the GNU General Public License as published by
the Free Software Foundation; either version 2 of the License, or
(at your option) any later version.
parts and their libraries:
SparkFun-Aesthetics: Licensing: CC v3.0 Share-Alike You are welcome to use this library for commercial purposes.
